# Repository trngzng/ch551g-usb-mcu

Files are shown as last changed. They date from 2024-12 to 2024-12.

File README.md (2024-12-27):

# About this repository
We have learned the USB MCU CH551G for educational purpose. All our documents, notes and source during the process will be stored here.

# About CH551 USB MCU
This MCU is 8-bit MCU with **built-in** USB device controller from https://www.wch.cn/. It's very cheap (**only 7.000VND - 0.31$**) but we can **directly** download the program by USB interface (*external debugger/programmer is not necessory*).

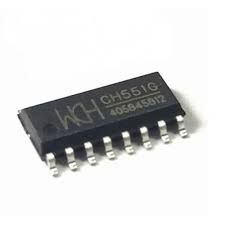
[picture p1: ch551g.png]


# How to use this repository
## Structure
```
+---docs
+---ref
|   \---USB_Relay_HID
\---src
    +---firmware
    \---hardware
```
1. ```docs```: contains the datasheet, notes,...
2. ```ref```: contains the reference documents and repo.
3. ```source```: 
   
   3.1. ```firmware```: contains the programs, examples, libraries,...
  
   3.2. ```hardware```: contains the schematics, PCBs of development kits and application boards.
## How to run the source
### Prerequisition
- Install [sdcc compiler](https://sourceforge.net/projects/sdcc/files/) and <a href="https://gnuwin32.sourceforge.net/packages/make.htm" target="_blank">Makefile</a>.
- Install [WCHISPTool](https://www.wch-ic.com/downloads/WCHISPTool_Setup_exe.html) for programs downloading.
### Compile the program
- Use following command for compile the program
```shell
sdcc -c main.c
sdcc main.rel
packihx main.rel > main.hex
```
- Or you can create the Makefile for automating it. All output files are in the ```output``` directory.
```make
# Define output directory
OUTPUT_DIR = output

# Compile each .c file into .rel files
hex: main.rel
	sdcc $(OUTPUT_DIR)\main.rel -o $(OUTPUT_DIR)\main.ihx

# Compile main.c to main.rel
$main.rel: main.c
	mkdir $(OUTPUT_DIR)
	sdcc -c main.c -o $(OUTPUT_DIR)\main.rel

all: hex
	packihx $(OUTPUT_DIR)\main.ihx > $(OUTPUT_DIR)\main.hex

clean:
	rmdir /s /q $(OUTPUT_DIR)
```
### Program the chip
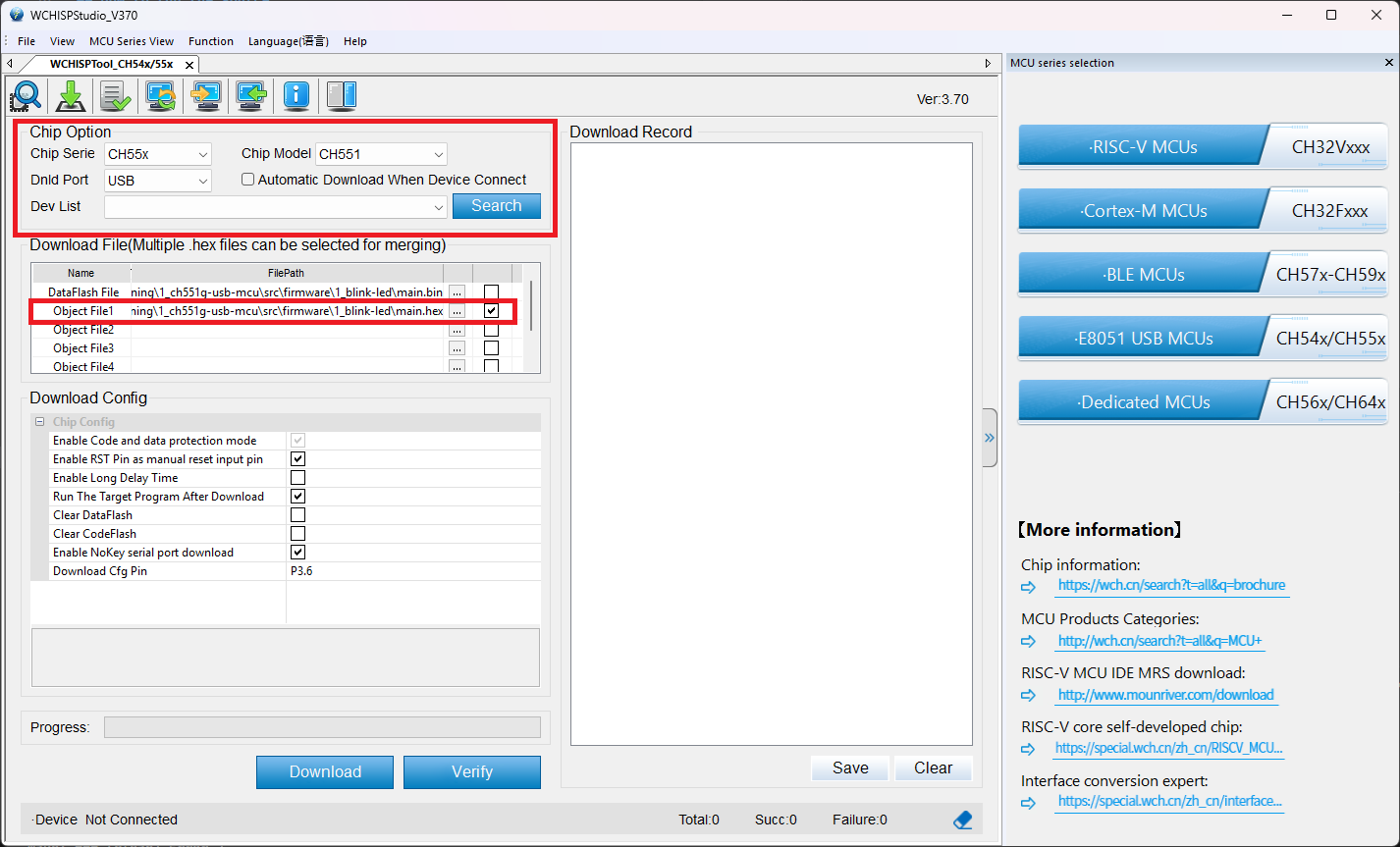
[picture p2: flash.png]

**Note:** *To program the chip:* Keep D+ pin of MCU in high level before suppling the power of MCU. It makes CH551G entering the programming mode.
# Contributors
1. Giang Phan Truong
2. Khoa Dong Thanh
3. Tuan Pham Ho Anh

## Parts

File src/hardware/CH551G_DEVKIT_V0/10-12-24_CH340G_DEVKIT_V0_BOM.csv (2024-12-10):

Reference | Value | Qty | Supply URL
U2 | CH551G | 1
U3 | RT9193_33GB | 1 | https://www.thegioiic.com/rt9193-33gb-ic-on-ap-3-3v-300ma
U1 | SMF05C | 1 | https://www.thegioiic.com/smf05c-esd-protection-diode-array-sot-363
J1 | USB_C_Receptacle | 1 | https://www.thegioiic.com/cong-usb-cai-3-1-type-c-24-chan-cong-90-do
C1 | 10uF/16V/0603 | 1 | https://www.thegioiic.com/tu-gom-0603-10uf-16v
C2,C3,C4,C5 | 100nF/16V/0603 | 4 | https://www.thegioiic.com/tu-gom-0603-100nf-0-1uf-16v
C6,C7 | 1uF/1206/16V | 2 | https://www.thegioiic.com/tu-tantalum-1uf-16v-1206-taja105k016rnj
C8 | 22nF/0603/50V | 1 | https://www.thegioiic.com/tu-gom-0603-22nf-50v
D1 | PWR | 1 | https://www.thegioiic.com/led-do-1206-dan-smd-trong-suot
D2 | USER LED | 1 | https://www.thegioiic.com/led-cam-0805-dan-smd-trong-suot-harvatek
FB1 | 100Ohm/900mA | 1 | https://www.thegioiic.com/bk2125hs101-t-ferrite-beads-100-ohm-0805
J2,J3 | Conn_01x08_Pin | 2 | https://www.thegioiic.com/hang-rao-duc-don-2-54mm-40-chan-1-hang-cao-11-2mm-xuyen-lo-ma-vang
R1,R2 | 470/1%/1_16W | 2 | https://www.thegioiic.com/dien-tro-470-ohm-0402-1-
R3,R5 | 100/1%/1_16W | 2 | https://www.thegioiic.com/dien-tro-100-ohm-0402-1-
R4 | 10K/1%/1_16W | 1 | https://www.thegioiic.com/dien-tro-10-kohm-0402-1-
SW1 | USER BUTTON | 1 | https://www.thegioiic.com/nut-nhan-3x4mm-cao-2-5mm-2-chan-smd
SW2 | RST | 1 | https://www.thegioiic.com/nut-nhan-3x4mm-cao-2-5mm-2-chan-smd
SW3 | FLASH | 1 | https://www.thegioiic.com/nut-nhan-3x4mm-cao-2-5mm-2-chan-smd

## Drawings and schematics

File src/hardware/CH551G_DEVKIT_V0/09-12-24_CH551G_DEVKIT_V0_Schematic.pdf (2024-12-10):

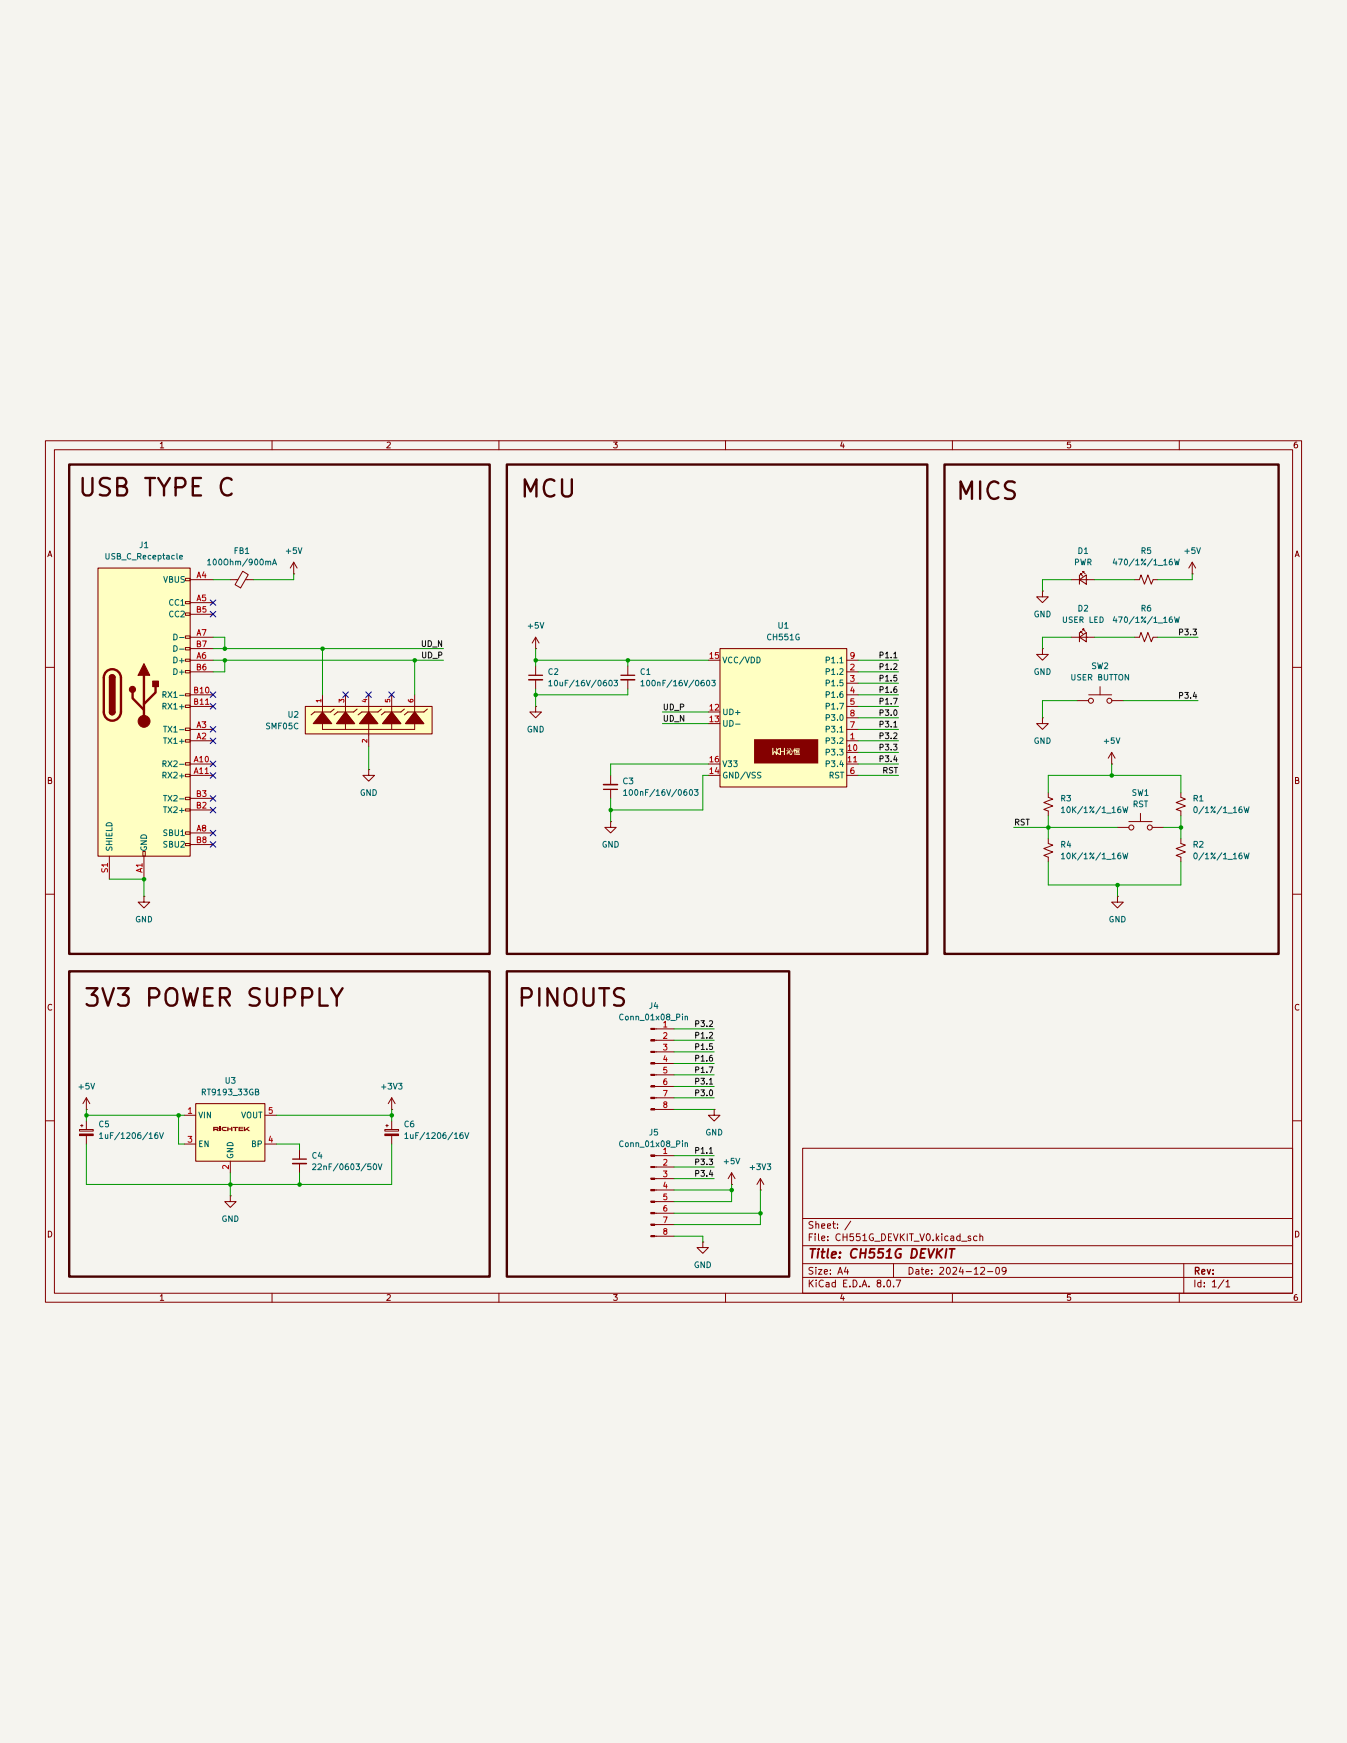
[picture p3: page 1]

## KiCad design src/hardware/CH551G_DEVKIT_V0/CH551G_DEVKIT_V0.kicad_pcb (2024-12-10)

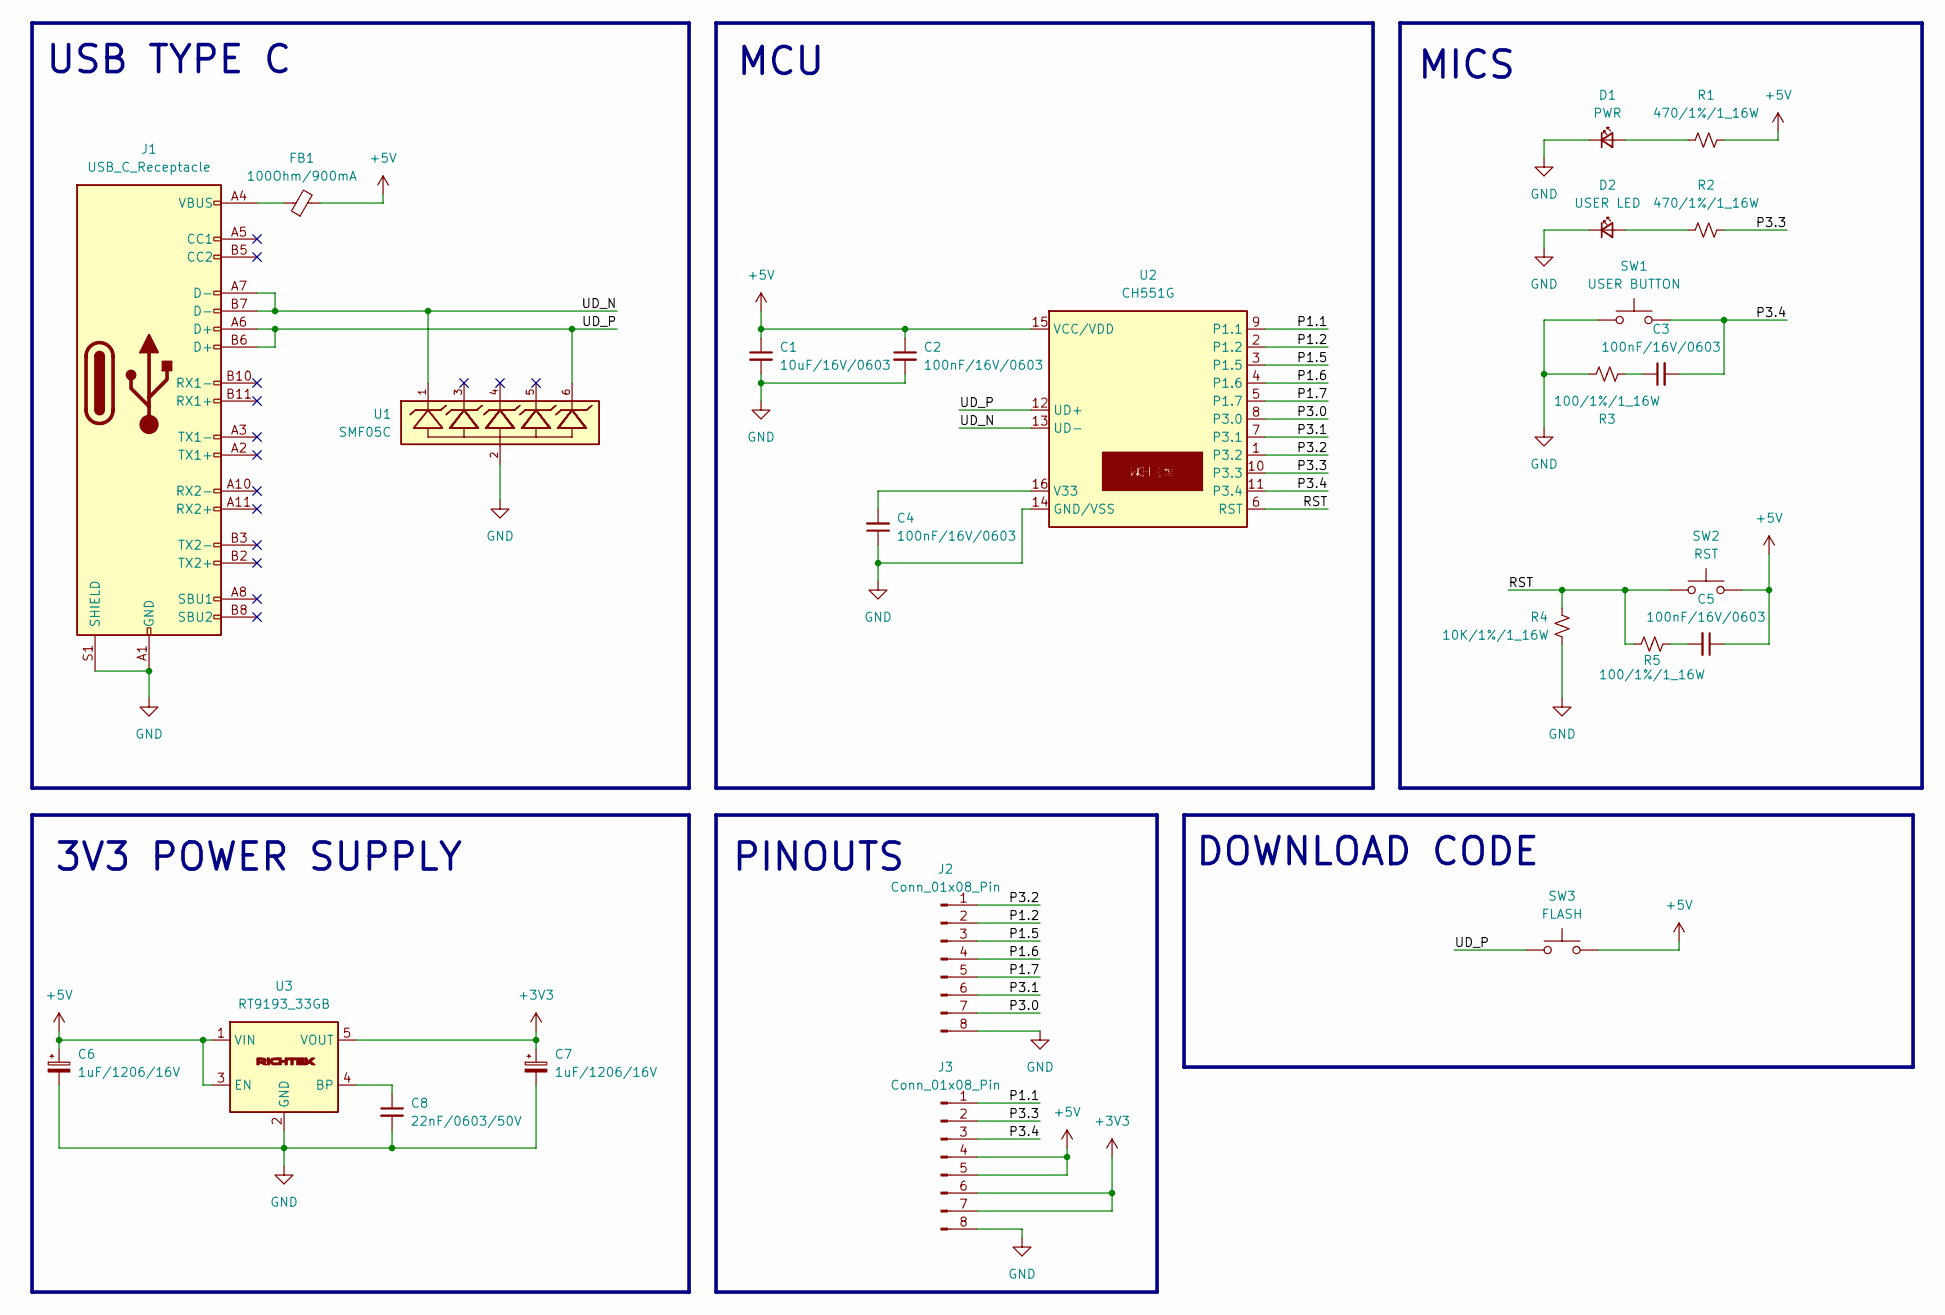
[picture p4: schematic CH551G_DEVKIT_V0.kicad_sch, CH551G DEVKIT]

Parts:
C1: 10uF/16V/0603; C_0603_1608Metric
C2, C3, C4, C5: 100nF/16V/0603; C_0603_1608Metric
C6, C7: 1uF/1206/16V; C_1206_3216Metric
C8: 22nF/0603/50V; C_0603_1608Metric
D1: PWR; LED_0805_2012Metric
D2: USER LED; LED_0805_2012Metric
FB1: 100Ohm/900mA; L_0805_2012Metric
J1: USB_C_Receptacle; USB_C_Receptacle_Amphenol_12401548E4-2A
J2, J3: Conn_01x08_Pin; PinHeader_1x08_P2.54mm_Vertical
R1, R2: 470/1%/1_16W; R_0402_1005Metric
R3, R5: 100/1%/1_16W; R_0402_1005Metric
R4: 10K/1%/1_16W; R_0402_1005Metric
SW1: USER BUTTON; SW_SMD
SW2: RST; SW_SMD
SW3: FLASH; SW_SMD
U1: SMF05C; SOT-363_SC-70-6
U2: CH551G; SOIC-16_3.9x9.9mm_P1.27mm
U3: RT9193_33GB; SOT-23-5

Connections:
+3V3: C7.1, J3.6, J3.7, U3.5 (VOUT)
+5V: C1.1, C2.1, C5.1, C6.1, FB1.2, J3.4, J3.5, R1.2, SW2.2, SW3.2, U2.15 (VCC/VDD), U3.1 (VIN), U3.3 (EN)
/P1.1: J3.1, U2.9 (P1.1)
/P1.2: J2.2, U2.2 (P1.2)
/P1.5: J2.3, U2.3 (P1.5)
/P1.6: J2.4, U2.4 (P1.6)
/P1.7: J2.5, U2.5 (P1.7)
/P3.0: J2.7, U2.8 (P3.0)
/P3.1: J2.6, U2.7 (P3.1)
/P3.2: J2.1, U2.1 (P3.2)
/P3.3: J3.2, R2.2, U2.10 (P3.3)
/P3.4: C3.2, J3.3, SW1.1, U2.11 (P3.4)
/RST: R4.2, R5.1, SW2.1, U2.6 (RST)
/UD_N: J1.A7 (D-), J1.B7 (D-), U1.1, U2.13 (UD-)
/UD_P: J1.A6 (D+), J1.B6 (D+), SW3.1, U1.6, U2.12 (UD+)
GND: C1.2, C2.2, C4.1, C6.2, C7.2, C8.2, D1.1 (K), D2.1 (K), J1.A1 (GND), J1.A12 (GND), J1.B1 (GND), J1.B12 (GND), J1.S1 (SHIELD), J2.8, J3.8, R3.2, R4.1, SW1.2, U1.2, U2.14 (GND/VSS), U3.2 (GND)
unnamed: C3.1, R3.1
unnamed: C5.2, R5.2
unnamed: D1.2 (A), R1.1
unnamed: D2.2 (A), R2.1
unnamed: FB1.1, J1.A4 (VBUS), J1.A9 (VBUS), J1.B4 (VBUS), J1.B9 (VBUS)
unnamed: C4.2, U2.16 (V33)
unnamed: C8.1, U3.4 (BP)

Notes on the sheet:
3V3 POWER SUPPLY
DOWNLOAD CODE
PINOUTS
MICS
USB TYPE C
MCU

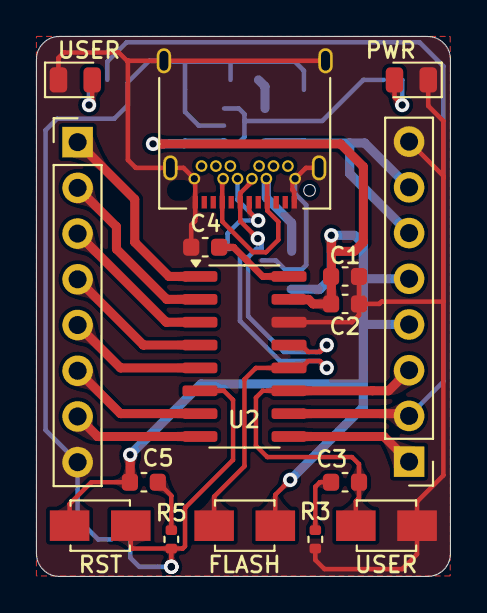
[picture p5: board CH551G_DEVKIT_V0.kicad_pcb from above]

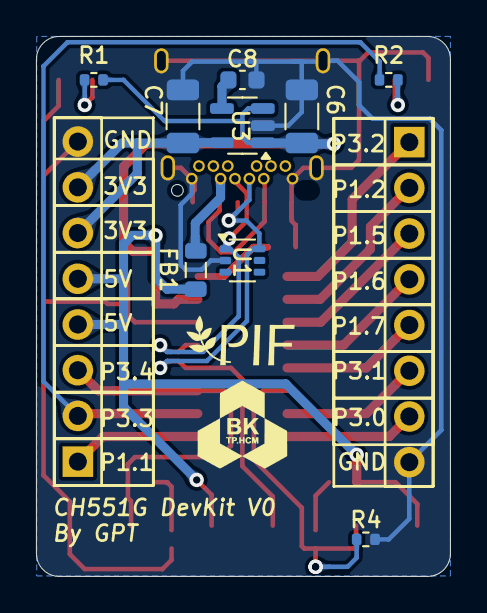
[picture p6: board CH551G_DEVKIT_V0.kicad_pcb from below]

Board: 2 copper layers, 23.0 x 30.0 mm, 25 parts (9 on the bottom side), 23 nets.

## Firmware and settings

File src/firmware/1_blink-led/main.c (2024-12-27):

/**
 * @file       main.c
 * @copyright  Copyright (C) 2024 GNG. All rights reserved.
 * @license    None.
 * @version    v1.0.0
 * @date       2024-12-26
 * @author     Giang Phan Truong
 *             
 * @brief      The first lesson: Blink USER led on V0 DevKit.
 *             
 * @note       For educational purpose only.
 */

/* Includes ----------------------------------------------------------- */
#include "ch552.h"
/* Private defines ---------------------------------------------------- */

/* Private enumerate/structure ---------------------------------------- */

/* Private macros ----------------------------------------------------- */

/* Public variables --------------------------------------------------- */

/* Private variables -------------------------------------------------- */

/* Private function prototypes ---------------------------------------- */
/**
 * @brief  Delay the processing using timer overflow
 *
 * @param[in]     ms  Delay time in microsecond
 *
 * @return  
 *  - none
 */
static void delay_ms(uint16_t ms);
/* Function definitions ----------------------------------------------- */
void main(void)
{
  /* Clock configuration fCLK = 24MHz  */
	SAFE_MOD = 0x55;  // Enter the safe mode
	SAFE_MOD = 0xAA;
	CLOCK_CFG = 0x86; // Write new value refer the Table in the datasheet
	SAFE_MOD = 0x00;  // Terminate the safe mode

  /* Configure P3.3: Output, push-pull */
  P3_MOD_OC &= ~(1 << 3);
	P3_DIR_PU |= (1 << 3);

  while(1)
  {
    P3 |= (1 << 3);
    delay_ms(1000);
    P3 &= ~(1 << 3);
    delay_ms(1000);
  }
}
/* Private definitions ------------------------------------------------ */
static void delay_ms(uint16_t ms)
{
	TMOD |= (1 << bT1_M0);	// 16-bit timer mode

	while (ms) 
  {
    // Timer frequency is Fsys/12 = 2Mhz = 0.5us
		TH0 = 0;   // Timer counter = 2000
		TL0 = 0;
		TR0 = 1;   // Start Timer0
		while ((TH0 << 8 | TL0) < 2000);
		TR0 = 0;   // Stop Timer0
		--ms;
	}
}

/* End of file -------------------------------------------------------- */

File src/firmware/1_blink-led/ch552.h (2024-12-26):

/*--------------------------------------------------------------------------
CH552.H
Header file for CH552 microcontrollers.
****************************************
**  Copyright  (C)  W.ch  1999-2016   **
**  Web:              http://wch.cn   **
****************************************
--------------------------------------------------------------------------*/

// 3 blocks: __BASE_TYPE__, __CH552_H__, __USB_DEF__


#ifndef __CH552_H__
#define __CH552_H__

#include <compiler.h>
#include <stdint.h>

#ifdef __cplusplus
extern "C" {
#endif

/*----- SFR --------------------------------------------------------------*/
/*  sbit are bit addressable, others are byte addressable */

/*  System Registers  */
SFR(PSW            ,  0xD0);        // program status word
 SBIT(CY           ,  0xD0,7);       // carry flag
 SBIT(AC           ,  0xD0,6);       // auxiliary carry flag
 SBIT(F0           ,  0xD0,5);       // bit addressable general purpose flag 0
 SBIT(RS1          ,  0xD0,4);       // register R0-R7 bank selection high bit
 SBIT(RS0          ,  0xD0,3);       // register R0-R7 bank selection low bit
#define MASK_PSW_RS       0x18      // bit mask of register R0-R7 bank selection
// RS1 & RS0: register R0-R7 bank selection
//    00 - bank 0, R0-R7 @ address 0x00-0x07
//    01 - bank 1, R0-R7 @ address 0x08-0x0F
//    10 - bank 2, R0-R7 @ address 0x10-0x17
//    11 - bank 3, R0-R7 @ address 0x18-0x1F
 SBIT(OV           ,  0xD0,2);       // overflow flag
 SBIT(F1           ,  0xD0,1);       // bit addressable general purpose flag 1
 SBIT(P            ,  0xD0,0);       // ReadOnly: parity flag
SFR(ACC            ,  0xE0);        // accumulator
SFR(B              ,  0xF0);        // general purpose register B
SFR(SP             ,  0x81);        // stack pointer
//sfr16 DPTR          = 0x82;         // DPTR pointer, little-endian
SFR(DPL            ,  0x82);        // data pointer low
SFR(DPH            ,  0x83);        // data pointer high
SFR(SAFE_MOD       ,  0xA1);        // WriteOnly: writing safe mode
//sfr CHIP_ID         = 0xA1;         // ReadOnly: reading chip ID
#define CHIP_ID           SAFE_MOD
SFR(GLOBAL_CFG     ,  0xB1);        // global config, Write@SafeMode
#define bBOOT_LOAD        0x20      // ReadOnly: boot loader status for discriminating BootLoader or Application: set 1 by power on reset, clear 0 by software reset
#define bSW_RESET         0x10      // software reset bit, auto clear by hardware
#define bCODE_WE          0x08      // enable flash-ROM (include code & Data-Flash) being program or erasing: 0=writing protect, 1=enable program and erase
#define bDATA_WE          0x04      // enable Data-Flash (flash-ROM data area) being program or erasing: 0=writing protect, 1=enable program and erase
#define bLDO3V3_OFF       0x02      // disable 5V->3.3V LDO: 0=enable LDO for USB and internal oscillator under 5V power, 1=disable LDO, V33 pin input external 3.3V power
#define bWDOG_EN          0x01      // enable watch-dog reset if watch-dog timer overflow: 0=as timer only, 1=enable reset if timer overflow

/* Clock and Sleep and Power Registers */
SFR(PCON           ,  0x87);        // power control and reset flag
#define SMOD              0x80      // baud rate selection for UART0 mode 1/2/3: 0=slow(Fsys/128 @mode2, TF1/32 @mode1/3, no effect for TF2),
                                    //   1=fast(Fsys/32 @mode2, TF1/16 @mode1/3, no effect for TF2)
#define bRST_FLAG1        0x20      // ReadOnly: recent reset flag high bit
#define bRST_FLAG0        0x10      // ReadOnly: recent reset flag low bit
#define MASK_RST_FLAG     0x30      // ReadOnly: bit mask of recent reset flag
#define RST_FLAG_SW       0x00
#define RST_FLAG_POR      0x10
#define RST_FLAG_WDOG     0x20
#define RST_FLAG_PIN      0x30
// bPC_RST_FLAG1 & bPC_RST_FLAG0: recent reset flag
//    00 - software reset, by bSW_RESET=1 @(bBOOT_LOAD=0 or bWDOG_EN=1)
//    01 - power on reset
//    10 - watch-dog timer overflow reset
//    11 - external input manual reset by RST pin
#define GF1               0x08      // general purpose flag bit 1
#define GF0               0x04      // general purpose flag bit 0
#define PD                0x02      // power-down enable bit, auto clear by wake-up hardware
SFR(CLOCK_CFG      ,  0xB9);        // system clock config: lower 3 bits for system clock Fsys, Write@SafeMode
#define bOSC_EN_INT       0x80      // internal oscillator enable and original clock selection: 1=enable & select internal clock, 0=disable & select external clock
#define bOSC_EN_XT        0x40      // external oscillator enable, need quartz crystal or ceramic resonator between XI and XO pins
#define bWDOG_IF_TO       0x20      // ReadOnly: watch-dog timer overflow interrupt flag, cleared by reload watch-dog count or auto cleared when MCU enter interrupt routine
#define bROM_CLK_FAST     0x10      // flash-ROM clock frequency selection: 0=normal(for Fosc>=16MHz), 1=fast(for Fosc<16MHz)
#define bRST              0x08      // ReadOnly: pin RST input
#define bT2EX_            0x08      // alternate pin for T2EX
#define bCAP2_            0x08      // alternate pin for CAP2
#define MASK_SYS_CK_SEL   0x07      // bit mask of system clock Fsys selection
/*
   Fxt = 24MHz(8MHz~25MHz for non-USB application), from external oscillator @XI&XO
   Fosc = bOSC_EN_INT ? 24MHz : Fxt
   Fpll = Fosc * 4 => 96MHz (32MHz~100MHz for non-USB application)
   Fusb4x = Fpll / 2 => 48MHz (Fixed)
              MASK_SYS_CK_SEL[2] [1] [0]
   Fsys = Fpll/3   =  32MHz:  1   1   1
   Fsys = Fpll/4   =  24MHz:  1   1   0
   Fsys = Fpll/6   =  16MHz:  1   0   1
   Fsys = Fpll/8   =  12MHz:  1   0   0
   Fsys = Fpll/16  =   6MHz:  0   1   1
   Fsys = Fpll/32  =   3MHz:  0   1   0
   Fsys = Fpll/128 = 750KHz:  0   0   1
   Fsys = Fpll/512 =187.5KHz: 0   0   0
*/
SFR(WAKE_CTRL      ,  0xA9);        // wake-up control, Write@SafeMode
#define bWAK_BY_USB       0x80      // enable wake-up by USB event
#define bWAK_RXD1_LO      0x40      // enable wake-up by RXD1 low level
#define bWAK_P1_5_LO      0x20      // enable wake-up by pin P1.5 low level
#define bWAK_P1_4_LO      0x10      // enable wake-up by pin P1.4 low level
#define bWAK_P1_3_LO      0x08      // enable wake-up by pin P1.3 low level
#define bWAK_RST_HI       0x04      // enable wake-up by pin RST high level
#define bWAK_P3_2E_3L     0x02      // enable wake-up by pin P3.2 (INT0) edge or pin P3.3 (INT1) low level
#define bWAK_RXD0_LO      0x01      // enable wake-up by RXD0 low level
SFR(RESET_KEEP     ,  0xFE);        // value keeper during reset
SFR(WDOG_COUNT     ,  0xFF);        // watch-dog count, count by clock frequency Fsys/65536
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

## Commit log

2024-12-26 update(MAIN): Blink LED with 1s period
2024-12-27 update(TIMER): Change timer0 config to 16-bit counter
